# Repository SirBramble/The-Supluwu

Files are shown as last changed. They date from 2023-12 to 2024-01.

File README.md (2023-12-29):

# The Supluwu

A voltage converter for 3D printers.

## Motivation

When modifying a 3D printer, sometimes you need smaller Voltages to run for example a Raspberry PI or 12V Fans. Smaller buck converter modules are useful but can be hard to mount or connect multiple devices to. The Supluwu is a small board meant to fix this.

## Features

The Supluwu features 2 Voltage rails with 5V and 12V. Each Voltage Rail is capable of 5A and is spread out over 3 Terminals. The Input of each Rail is Fused with a 20mmx5mm glass fuse. The Input Voltage can be anything from 14-30V, so the typical 24V power supply of a 3D printer works fine. Each Terminal has a indicator LED, that lights up, if the buck converter is working properly.

## Heat Management

Heat Produced by the Regulator is spread out to the PCB and can be carried away by the PCB mounted [14mmx14mm heat sinks](https://www.amazon.de/-/en/gp/product/B09DKJPZRX?th=1).

## Pictures

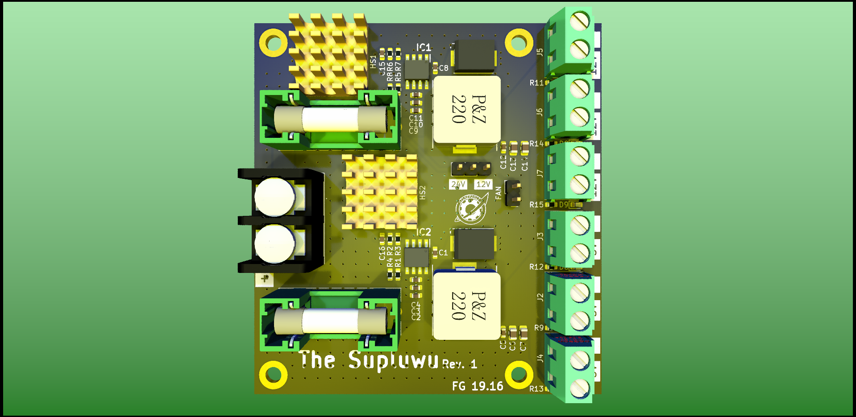
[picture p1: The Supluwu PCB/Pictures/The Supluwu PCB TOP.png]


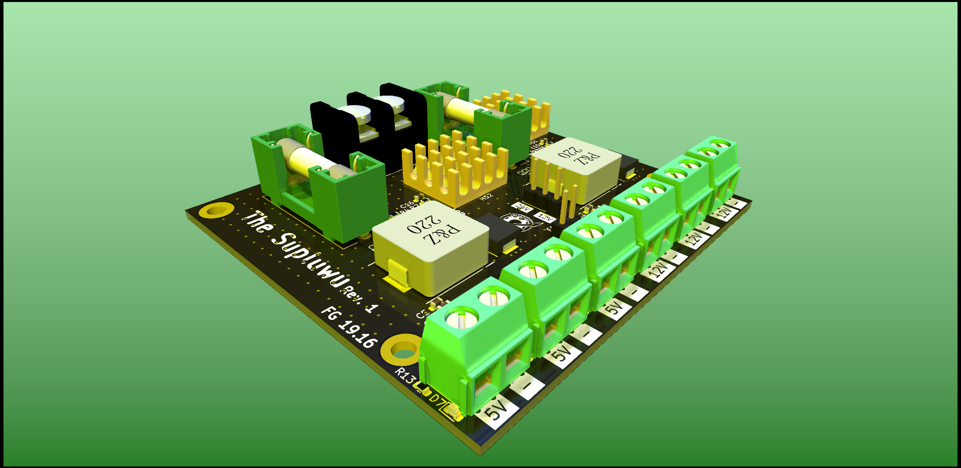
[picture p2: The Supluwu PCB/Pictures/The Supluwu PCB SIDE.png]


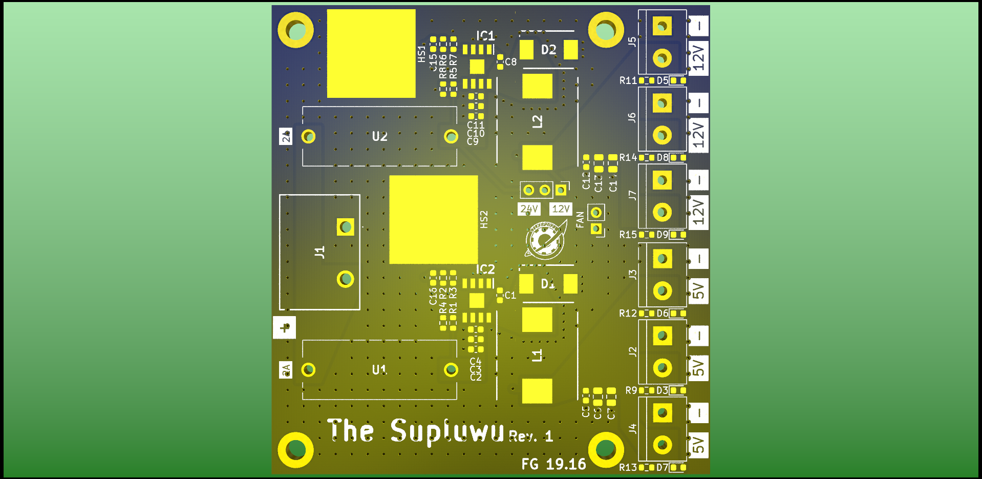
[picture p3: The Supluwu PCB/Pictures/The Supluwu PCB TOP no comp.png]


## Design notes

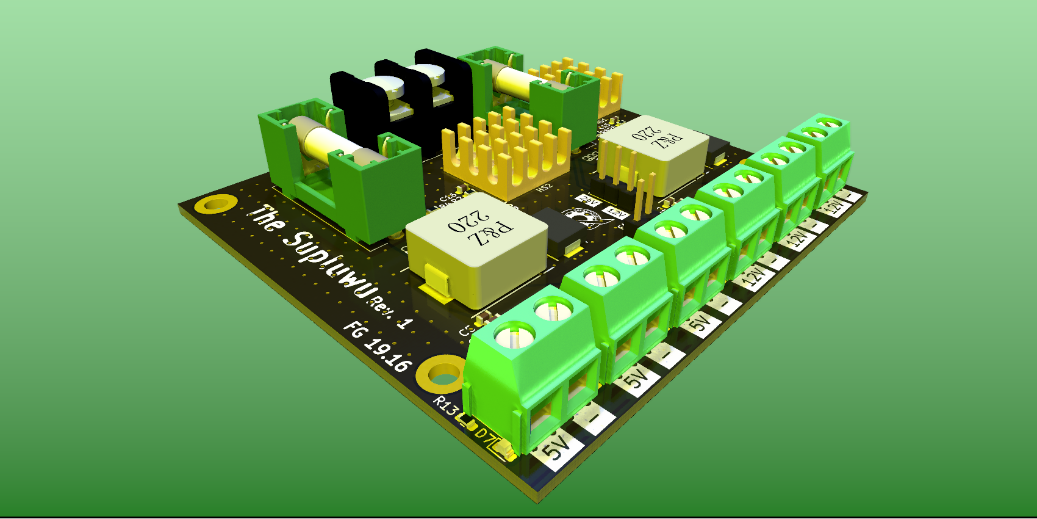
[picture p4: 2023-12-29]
The Supluwu PCB/Pictures/The Supluwu PCB TN.png

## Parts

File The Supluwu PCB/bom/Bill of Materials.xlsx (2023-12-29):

Designator | Footprint | Value | Description | Part Nr. | Quantity | Price/pcs. | Price
C1, C8 | 0603 | 10nF | 5% 50V Capacitor | 80-C0603C103J5RACTM (https://www.mouser.de/ProductDetail/KEMET/C0603C103J5RACTM?qs=sGAEpiMZZMvsSlwiRhF8quIsB1QHp5lfftsENRi1zqo%3D) | 2 | 0.09 € | 0.19 €
C10, C2, C3, C9 | 0603 | 4u7 | 10% 25V Capacitor | 81-GRM188C81E475KE1D (https://www.mouser.de/ProductDetail/81-GRM188C81E475KE1D) | 4 | 0.24 € | 0.97 €
C11, C12, C4, C5 | 0603 | 100n | Generic 1% Capacitor | Generic | 4 | 0.01 € | 0.04 €
C13, C14, C6, C7 | 0805 | 22uF | 20% 25V Capacitor | 187-CL21A226MAYNNWE (https://www.mouser.de/ProductDetail/187-CL21A226MAYNNWE) | 4 | 0.30 € | 1.19 €
C15, C16 | 0603 | 82pF | 5% 50V Capacitor | 581-06035A820JAT4A (https://www.mouser.de/ProductDetail/KYOCERA-AVX/06035A820JAT4A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) | 2 | 0.09 € | 0.19 €
D1, D2 | DIOM7959X250N | B550C-13-F | 50V 5A Diode | 621-B550C-F (https://www.mouser.de/ProductDetail/Diodes-Incorporated/B550C-13-F?qs=UEP5Ic6BRave1jzuZzz4FA%3D%3D) | 2 | 0.52 € | 1.04 €
D3, D6, D7, | 0603 | LED_GREEN | Generic LED Greed | Generic | 3 | 0.05 € | 0.15 €
D5,D8,D9 | 0603 | LED_Yellow | Generic LED Yellow | Generic | 3 | 0.05 € | 0.15 €
IC1, IC2 | SOIC127P600X175-9N | RT6285GSP | 5A Buck Converter | 835-RT6285GSP (https://www.mouser.de/ProductDetail/Richtek/RT6285GSP?qs=amGC7iS6iy9ag0U80PgEbw%3D%3D) | 2 | 0.84 € | 1.67 €
J1 | 4DBP10702 | 4DB-P107-02 | Terminal Block Large | 571-14376676 (https://www.mouser.de/ProductDetail/TE-Connectivity/4DB-P107-02?qs=HIOJlr2Cjjgxt%2FCLkbzYNw%3D%3D) | 1 | 0.73 € | 0.73 €
J2, J3, J4, J5, J6, J7 | TerminalBlock_bornier-2_P5.08mm | 5V_OUT | Generic Terminal Block | Generic | 6 | 0.05 € | 0.30 €
J8 | PinHeader_1x03_P2.54mm_Vertical | V_Switch | Generic Pin Header | Generic | 1 | 0.05 € | 0.05 €
J9 | PinHeader_1x02_P2.54mm_Vertical | FAN | Generic Pin Header | Generic | 1 | 0.05 € | 0.05 €
L1, L2 | INDPM140128X650N | 15uH | 15uH 9A Inductor | 673-PA4343.153NLT (https://www.mouser.de/ProductDetail/Pulse-Electronics/PA4343.153NLT?qs=%2FzQKu7YvIMa1YhPbm59etw%3D%3D) | 2 | 1.66 € | 3.32 €
R11, R14, R15 | 0603 | 3k3 | 1% Resistor | 603-RT0603FRE073K3L (https://www.mouser.de/ProductDetail/YAGEO/RT0603FRE073K3L?qs=8cPjvKtxWv4e7c7t%252BTLsig%3D%3D) | 3 | 0.09 € | 0.28 €
R12, R13, R9 | 0603 | 1k | Generic 1% Resistor | Generic | 3 | 0.01 € | 0.03 €
R2, R6 | 0603 | 100k | Generic 1% Resistor | Generic | 2 | 0.01 € | 0.02 €
R3 | 0603 | 31.6k | 1% Resistor | 603-RT0603FRE0731K6L (https://www.mouser.de/ProductDetail/YAGEO/RT0603FRE0731K6L?qs=FxNwScCwyKcKv58rFou%2FcQ%3D%3D) | 1 | 0.09 € | 0.09 €
R7 | 0603 | 11.3k | 1% Resistor | 603-RT0603DRE0711K3L (https://www.mouser.de/ProductDetail/YAGEO/RT0603DRE0711K3L?qs=4CyHz7GXqShrtIPseYB4Tw%3D%3D) | 1 | 0.09 € | 0.09 €
U1, U2 | 0PTF0078P | 0PTF0078P | Fuse Holder 5x20 | 576-0PTF0078P (https://www.mouser.de/ProductDetail/Littelfuse/0PTF0078P?qs=Co4VkB5J4%2Fsczy6gG8s%2FsA%3D%3D) | 2 | 0.51 € | 1.02 €
 |  |  |  |  |  |  | 11.58 €

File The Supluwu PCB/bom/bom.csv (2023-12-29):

Designator | Footprint | Quantity | Value | LCSC Part #
C1, C8 | 0603 | 2 | 10nF
C10, C2, C3, C9 | 0603 | 4 | 4u7
C11, C12, C4, C5 | 0603 | 4 | 100n | C14663
C13, C14, C6, C7 | 0805 | 4 | 22uF | C45783
C15, C16 | 0603 | 2 | 82pF
D1, D2 | DIOM7959X250N | 2 | B550C-13-F
D3, D5, D6, D7, D8, D9 | 0603 | 6 | LED_GREEN
H1, H2, H3, H4 | MountingHole_3.2mm_M3_ISO7380_Pad | 4 | MountingHole_Pad
HS1, HS2 | 14x14mm PCB with VIA | 2 | Heatsink_Pad
IC1, IC2 | SOIC127P600X175-9N | 2 | RT6285GSP
J1 | 4DBP10702 | 1 | 4DB-P107-02
J2, J3, J4, J5, J6, J7 | TerminalBlock_bornier-2_P5.08mm | 6 | 5V_OUT
J8 | PinHeader_1x03_P2.54mm_Vertical | 1 | V_Switch
J9 | PinHeader_1x02_P2.54mm_Vertical | 1 | FAN
L1, L2 | INDPM140128X650N | 2 | 15uH
R1, R4, R5, R8 | 0603 | 4 | DNP
R11, R14, R15 | 0603 | 3 | 3k3
R12, R13, R9 | 0603 | 3 | 1k
R2, R6 | 0603 | 2 | 100k
R3 | 0603 | 1 | 31.6k
R7 | 0603 | 1 | 11.3k
U1, U2 | 0PTF0078P | 2 | 0PTF0078P

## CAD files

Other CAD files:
The Supluwu PCB/plot/The Supluwu PCB-B_Silkscreen.dxf
The Supluwu PCB/plot/The Supluwu PCB-F_Silkscreen.dxf

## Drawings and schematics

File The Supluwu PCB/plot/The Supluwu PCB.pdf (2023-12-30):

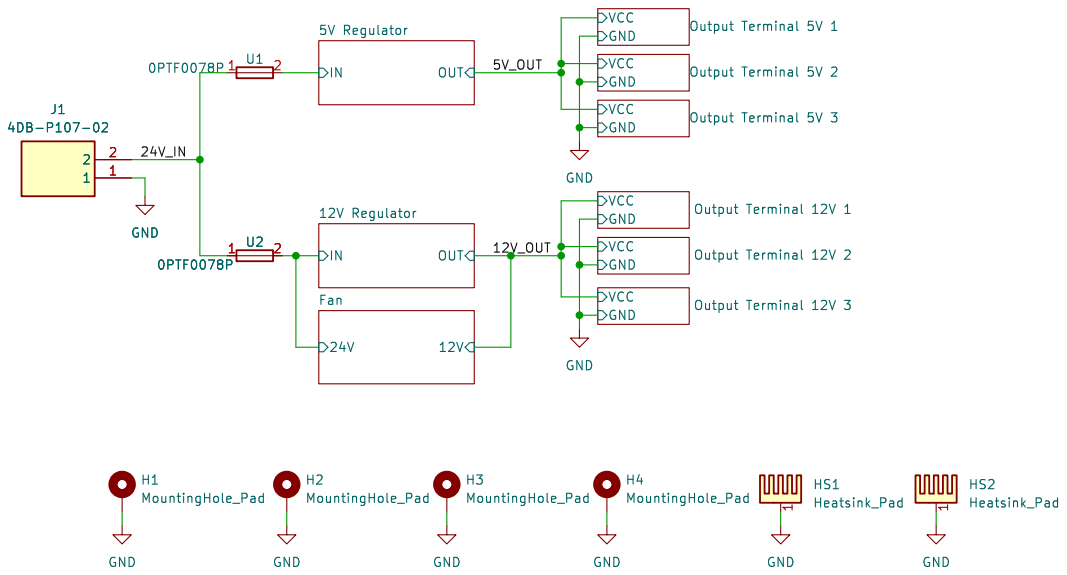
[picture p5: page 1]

Id: 1/10 Title: The Supluwu

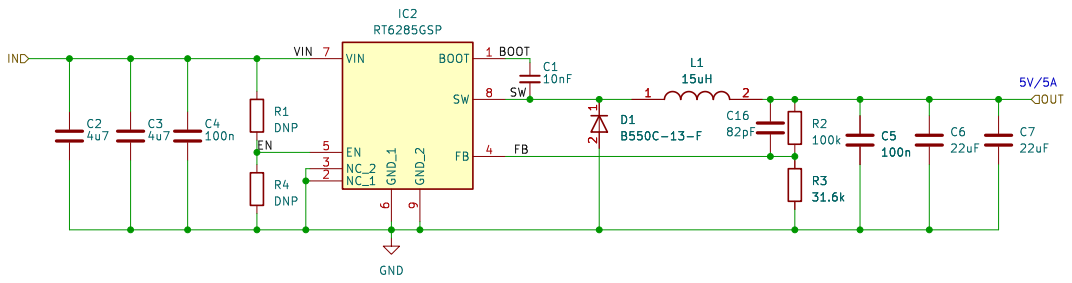
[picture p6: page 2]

Id: 2/10 Title: The Supluwu

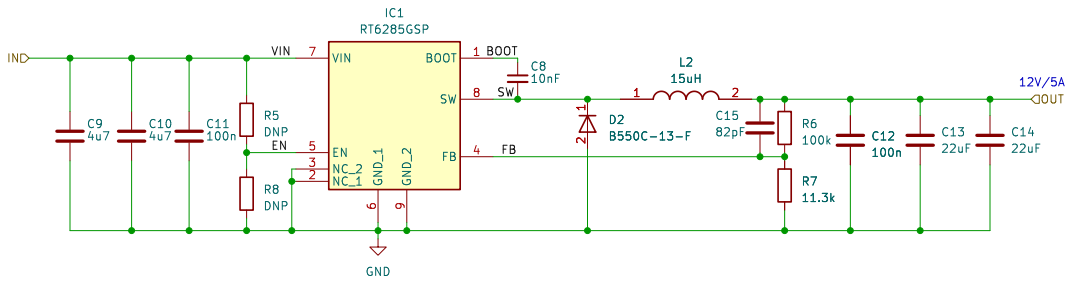
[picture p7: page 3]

Id: 3/10 Title: The Supluwu

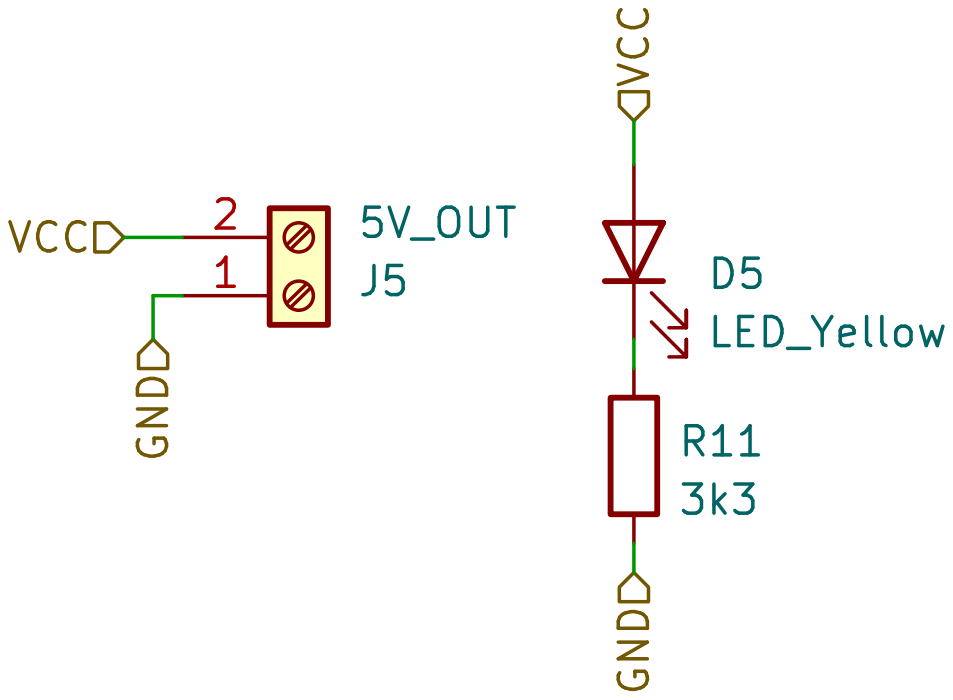
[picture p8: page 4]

Id: 4/10 Title: The Supluwu

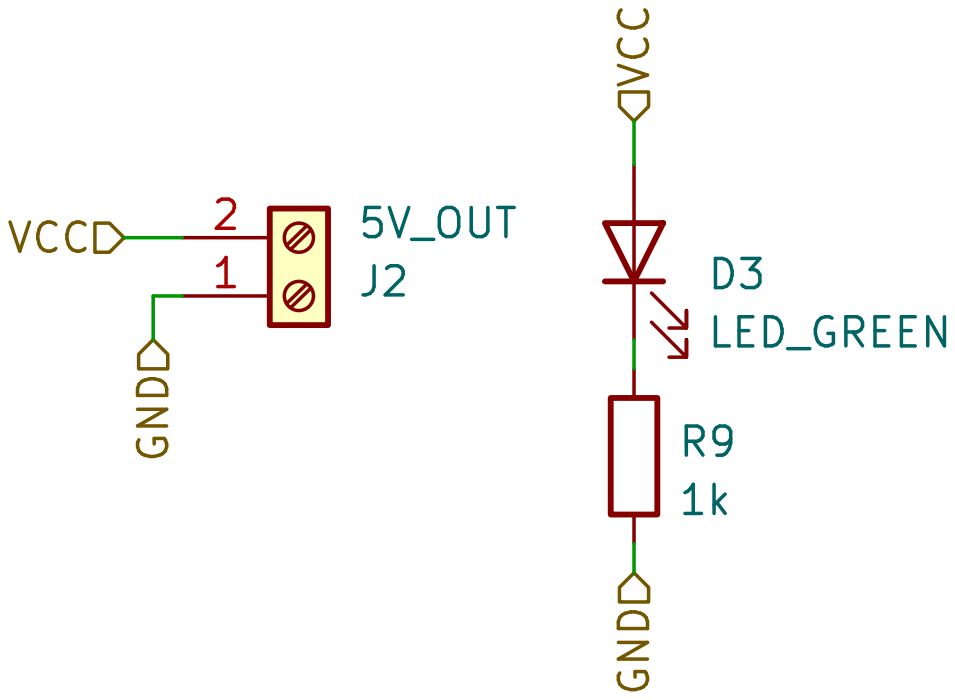
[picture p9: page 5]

Id: 5/10 Title: The Supluwu

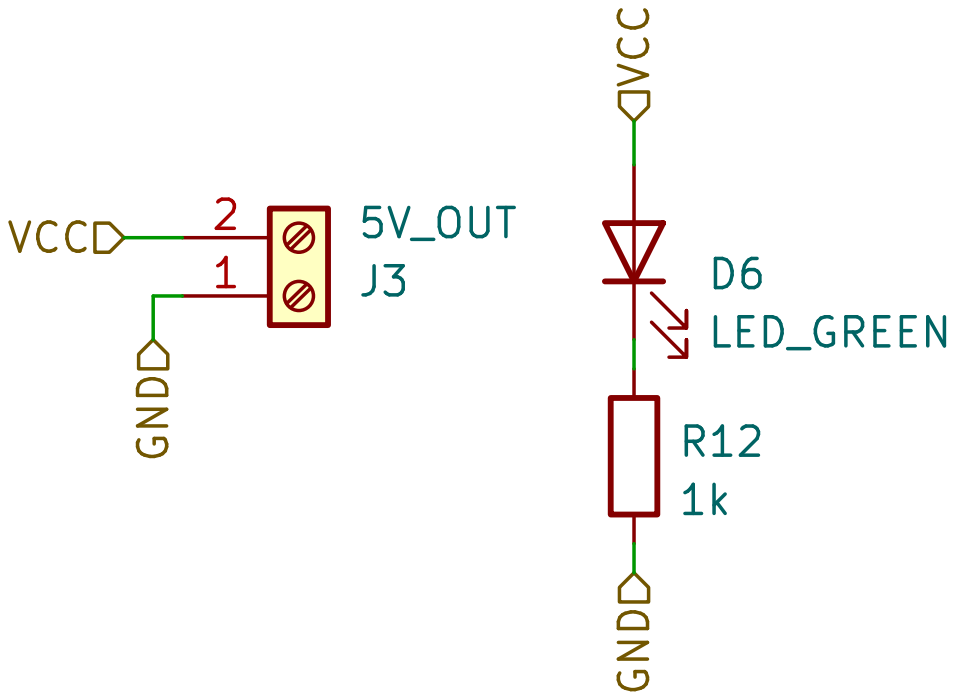
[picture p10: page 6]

Id: 6/10 Title: The Supluwu

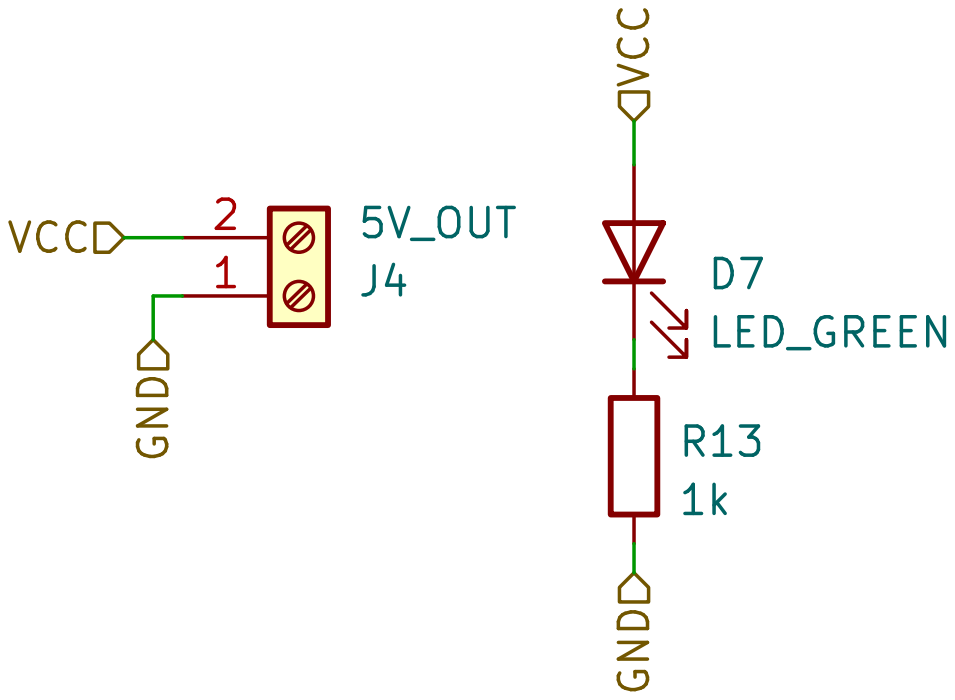
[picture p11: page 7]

Id: 7/10 Title: The Supluwu

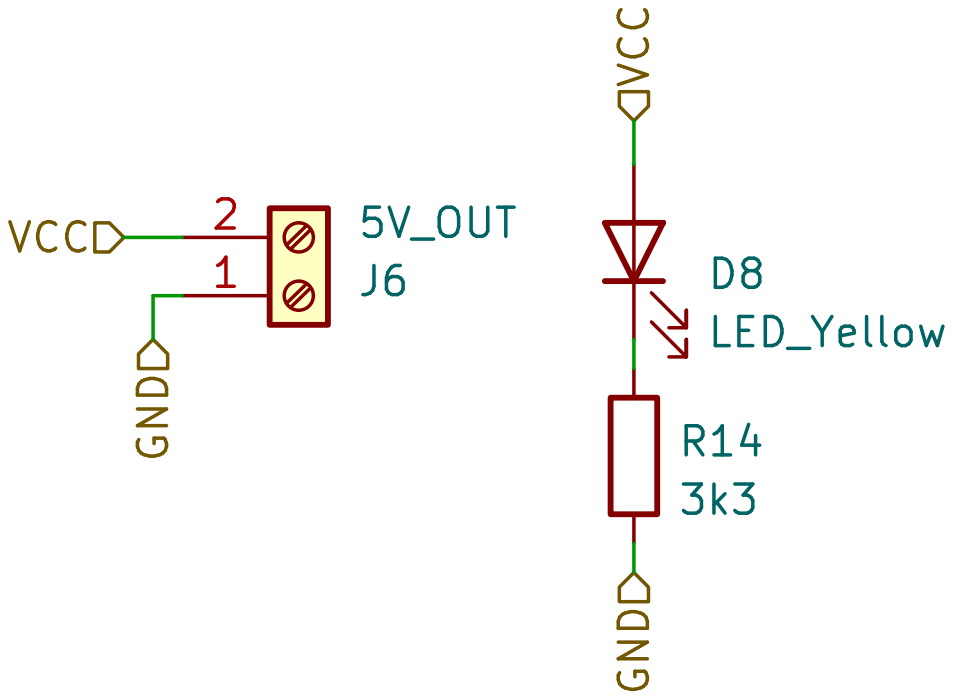
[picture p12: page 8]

Id: 8/10 Title: The Supluwu

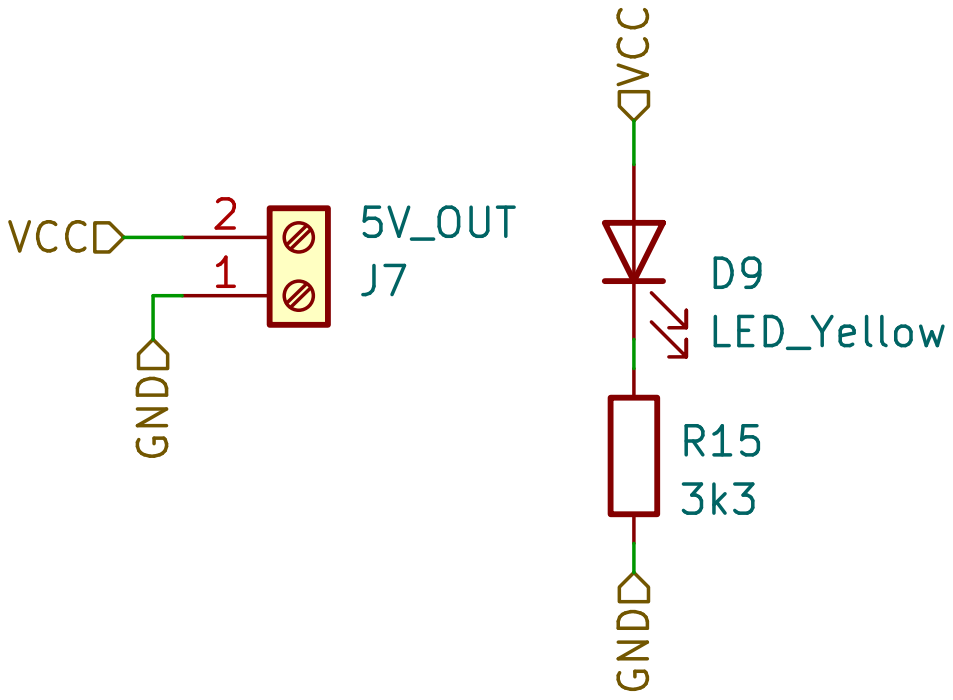
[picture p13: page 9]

Id: 9/10 Title: The Supluwu

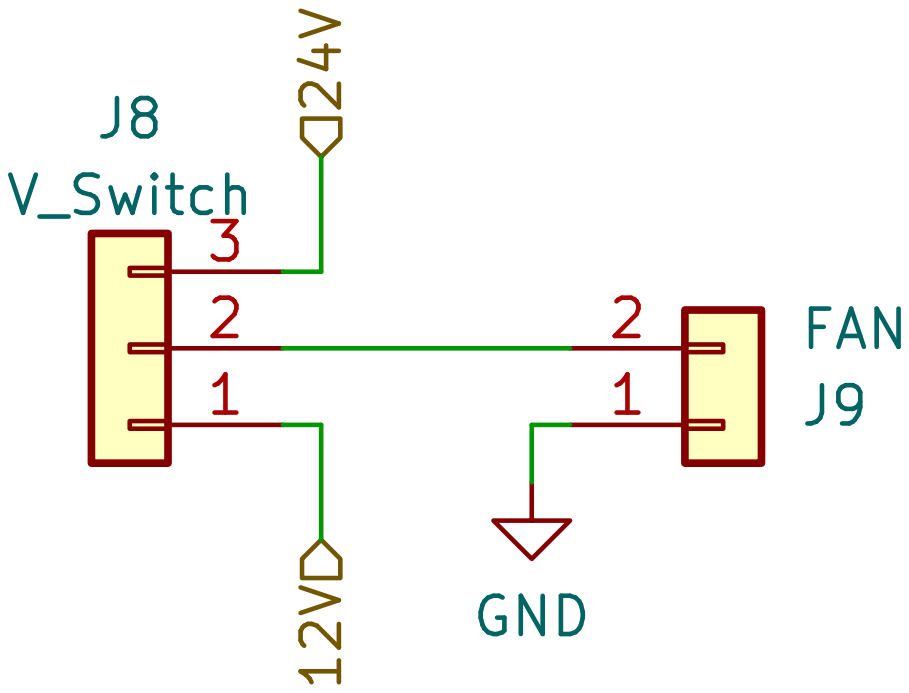
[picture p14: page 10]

Id: 10/10 Title: The Supluwu

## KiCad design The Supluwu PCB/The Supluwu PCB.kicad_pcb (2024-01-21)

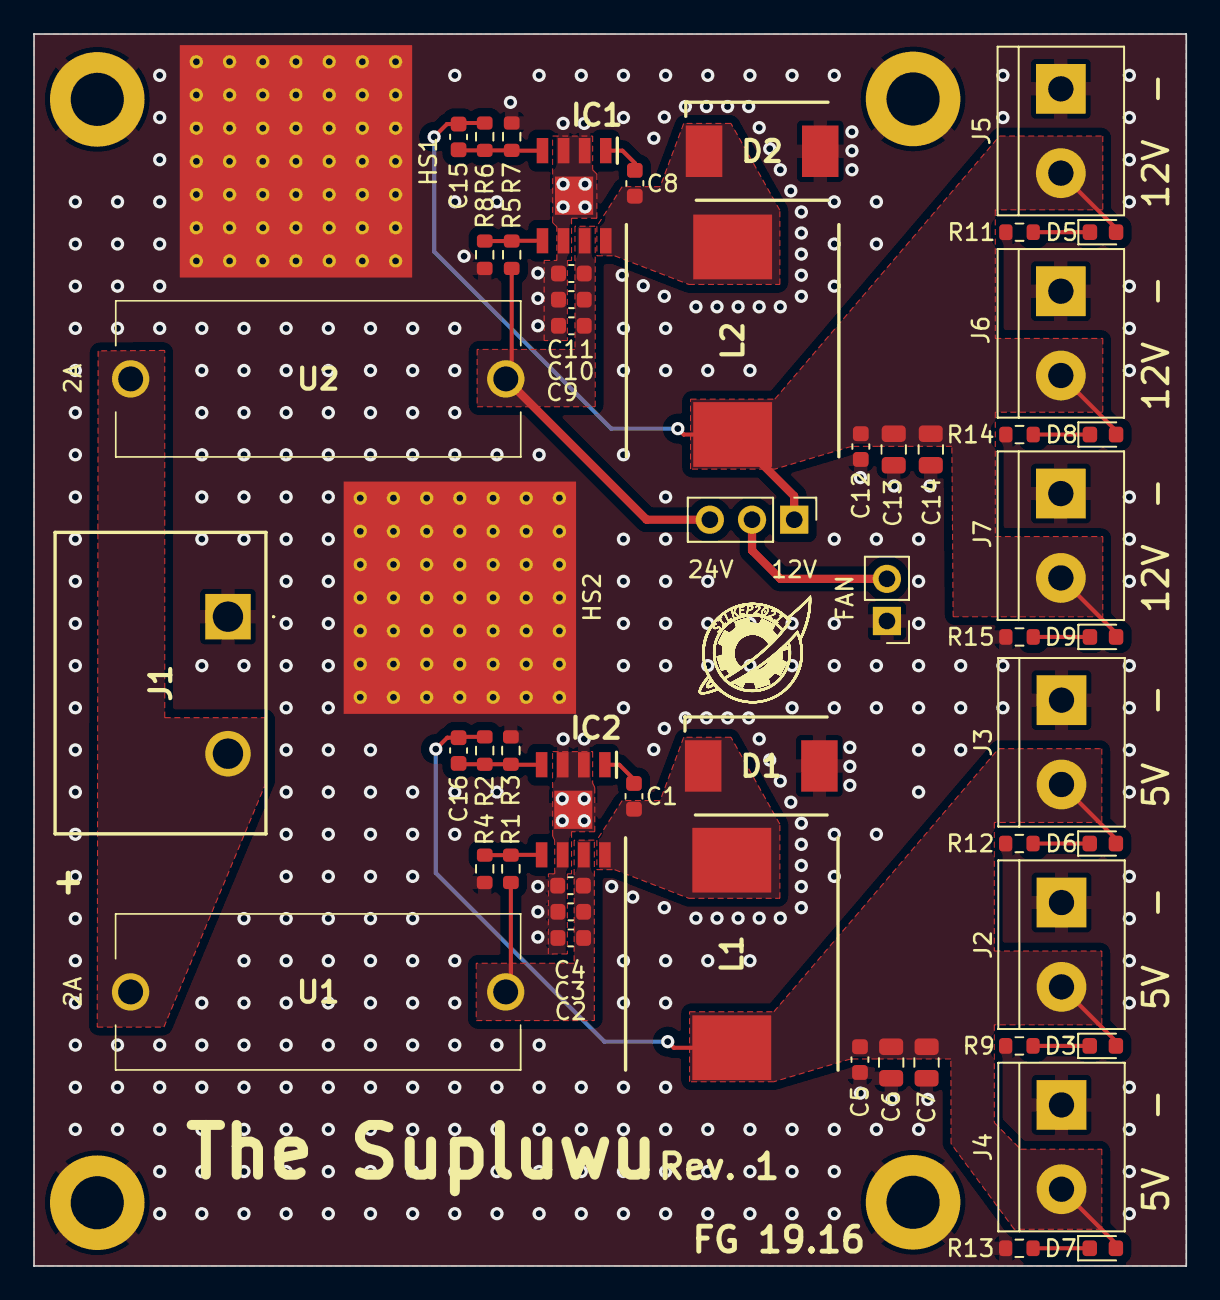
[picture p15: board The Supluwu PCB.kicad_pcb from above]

Board: 2 copper layers, 69.4 x 74.2 mm, 59 parts (0 on the bottom side), 21 nets.

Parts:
C1, C8: 10nF; C_0603_1608Metric
C2, C3, C9, C10: 4u7; C_0603_1608Metric
C4, C5, C11, C12: 100n; C_0603_1608Metric
C6, C7, C13, C14: 22uF; C_0805_2012Metric
C15, C16: 82pF; C_0603_1608Metric
D1, D2: B550C-13-F; DIOM7959X250N
D3, D6, D7: LED_GREEN; LED_0603_1608Metric
D5, D8, D9: LED_Yellow; LED_0603_1608Metric
H1, H2, H3, H4: MountingHole_Pad; MountingHole_3.2mm_M3_ISO7380_Pad
HS1, HS2: Heatsink_Pad; 14x14mm PCB with VIA
IC1, IC2: RT6285GSP; SOIC127P600X175-9N
J1: 4DB-P107-02; 4DBP10702
J2, J3, J4, J5, J6, J7: 5V_OUT; TerminalBlock_bornier-2_P5.08mm
J8: V_Switch; PinHeader_1x03_P2.54mm_Vertical
J9: FAN; PinHeader_1x02_P2.54mm_Vertical
L1, L2: 15uH; INDPM140128X650N
R1, R4, R5, R8: DNP; R_0603_1608Metric
R2, R6: 100k; R_0603_1608Metric
R3: 31.6k; R_0603_1608Metric
R7: 11.3k; R_0603_1608Metric
R9, R12, R13: 1k; R_0603_1608Metric
R11, R14, R15: 3k3; R_0603_1608Metric
U1, U2: 0PTF0078P

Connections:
/5V Regulator/BOOT: C1.1, IC2.1 (BOOT)
/5V Regulator/EN: IC2.5 (EN), R1.2, R4.1
/5V Regulator/FB: C16.2, IC2.4 (FB), R2.2, R3.1
/5V Regulator/SW: C1.2, D1.1 (K), IC2.8 (SW), L1.1
/5V Regulator/VIN: C2.1, C3.1, C4.1, IC2.7 (VIN), R1.1, U1.2
/5V_OUT: C5.1, C6.1, C7.1, C16.1, D3.2 (A), D6.2 (A), D7.2 (A), J2.2, J3.2, J4.2, L1.2, R2.1
/12V Regulator/BOOT: C8.1, IC1.1 (BOOT)
/12V Regulator/EN: IC1.5 (EN), R5.2, R8.1
/12V Regulator/FB: C15.2, IC1.4 (FB), R6.2, R7.1
/12V Regulator/SW: C8.2, D2.1 (K), IC1.8 (SW), L2.1
/12V Regulator/VIN: C9.1, C10.1, C11.1, IC1.7 (VIN), J8.3, R5.1, U2.2
/12V_OUT: C12.1, C13.1, C14.1, C15.1, D5.2 (A), D8.2 (A), D9.2 (A), J5.2, J6.2, J7.2, J8.1, L2.2, R6.1
/24V_IN: J1.2, U1.1, U2.1
GND: C2.2, C3.2, C4.2, C5.2, C6.2, C7.2, C9.2, C10.2, C11.2, C12.2, C13.2, C14.2, D1.2 (A), D2.2 (A), H1.1, H2.1, H3.1, H4.1, HS1.1, HS2.1, IC1.2 (NC_1), IC1.3 (NC_2), IC1.6 (GND_1), IC1.9 (GND_2), IC2.2 (NC_1), IC2.3 (NC_2), IC2.6 (GND_1), IC2.9 (GND_2), J1.1, J2.1, J3.1, J4.1, J5.1, J6.1, J7.1, J9.1, R3.2, R4.2, R7.2, R8.2, R9.2, R11.2, R12.2, R13.2, R14.2, R15.2
unnamed: D3.1 (K), R9.1
unnamed: D5.1 (K), R11.1
unnamed: D6.1 (K), R12.1
unnamed: D7.1 (K), R13.1
unnamed: D8.1 (K), R14.1
unnamed: D9.1 (K), R15.1
unnamed: J8.2, J9.2

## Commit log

2023-12-30 added Schematic printout
    [5V Regulator.kicad_sch]
2024-01-21 added 3D
    [5V Regulator.kicad_sch, The Supluwu PCB-B_Silkscreen.dxf, The Supluwu PCB-F_Silkscreen.dxf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]
